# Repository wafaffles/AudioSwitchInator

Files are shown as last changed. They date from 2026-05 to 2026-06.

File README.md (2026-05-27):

# Audioswitchinator
A multi input and output audio switch with an integrated, toggleable Hifi phono preamp

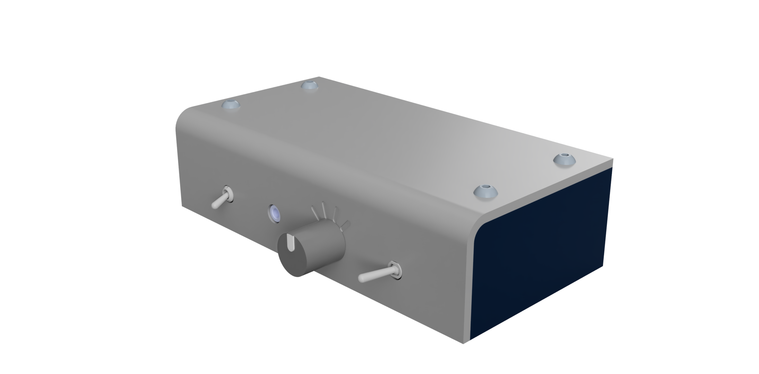
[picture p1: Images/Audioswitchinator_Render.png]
Render of Audioswitchinator in case


## Shortcuts
- [Features](#features)
- [What is it?](#what-is-it)
- [Resources](#resources)
- [Assembly](#assembly)
- [Bill Of Materials](#bill-of-materials)
- [Photos](#photos)

## Audioswitchinator Zine

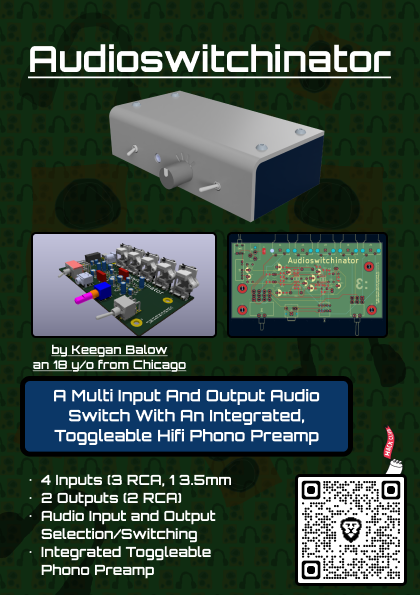
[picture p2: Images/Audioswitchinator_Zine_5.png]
Audioswitchinator Zine


## Features
- 4 Inputs
  - 3 RCA
  - 1 3.5mm
- 2 Outputs
  - 2 RCA
- Audio Input and Output Selection
- Integrated Toggleable Phono Preamp for a Turntable

## What is it?

The Audioswitchinator is a device that was made to allow me to route all of my audio inputs and outputs into one place on my desk so that I can easily change where my audio is coming from and going to without having to deal with changing the input on my speakers, changing the output on my computer, and my record player mainly. It features 4 inputs, 3 RCA and 1 3.5mm ports, and 2 ouputs, both being RCA ports. The first of the phono inputs is routed to a toggleable phono preamp, based on this design by [Elliott Sound Products](https://sound-au.com/project06.htm). The mixture of inputs and ports allows for easily compatibility with most audio products, as well as supporting smaller on the go inputs like a phone or other input device. While I only need 2 inputs and 2 outputs currently, the device features the extra inputs and outputs as my equipment arsenal expands or I want to test new products without fully removing the old ones.

The device features a power switch on the rear to power the integrated phono preamp, a switch on the front to enable routing of the turntable input through the phono preamp, a rotary switch to choose which input you would like to listen to, and a switch to choose between either of the two inputs.
It is powered using 12V via a 5.7mm barrell jack. It has a very low power draw of around 50mA at most so nearly any suitable 12V switching mode power supply should work well.

The case is fully 3d printed with use of a few M4 bolts and heatset inserts, but can easily be modified to thread directly into the plastic. The design resembles the design pattern of Schiit Audio products as I currently own a DAC and headphone amp and really like the design. The case is at largest 160x80, so it is easily printable on most 3D printers, being designed to print on my Bambu Labs A1 Mini.

## Resources

CAD Link: https://cad.onshape.com/documents/9e04128c642e582e05c8193e/w/29af00c33977f5103195c9e0/e/9dcbf64564f57b3e7e8e01ad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

CAD Files: [HERE](/Models)

ECAD Files: [HERE](/Models/ECAD/)

Production Files: [HERE](/Resources/)

## Assembly

You will need:
- PCB from files
- Soldering Iron & Solder
- All components from [BOM](https://docs.google.com/spreadsheets/d/1tNDlkv8S-ZhfvEyZw77WZDcWJRZpA8B7S98ZAzSkEbk/edit?usp=sharing.)
- Matching screwdriver to screw set (allen key in provided kit)
- Small pair of tweasers

To start, you will need to have access to a 3D printer with a build volume of at least 160x80mm and about 100-120g of filament of your choice.

You then need to order all the parts and PCB and have proper resources to solder these components. Once you have these, solder all components on as specified in the schematic.

Once soldered together where listed in the schematic, then with the bottom part of the case, insert the 8 heatset inserts if you choose not to modify the design to use those. To insert heatset inserts, get the largest tip that fits inside the heatset insert and install it on your soldering iron. Now, place the insert where it goes and insert the tip into the center of the insert snd heat it while applying slight downward force until it is flush with the surface. A small pair of tweasers may be helpful to reorient it.

Once all the heatset inserts are installed, you should be able to screw in the PCB, then screw on the top, and it should be working there!

## Bill Of Materials

Bill of Materials: [HERE](https://docs.google.com/spreadsheets/d/1tNDlkv8S-ZhfvEyZw77WZDcWJRZpA8B7S98ZAzSkEbk/edit?usp=sharing)

## Photos

Audioswitchinator PCB Schematic

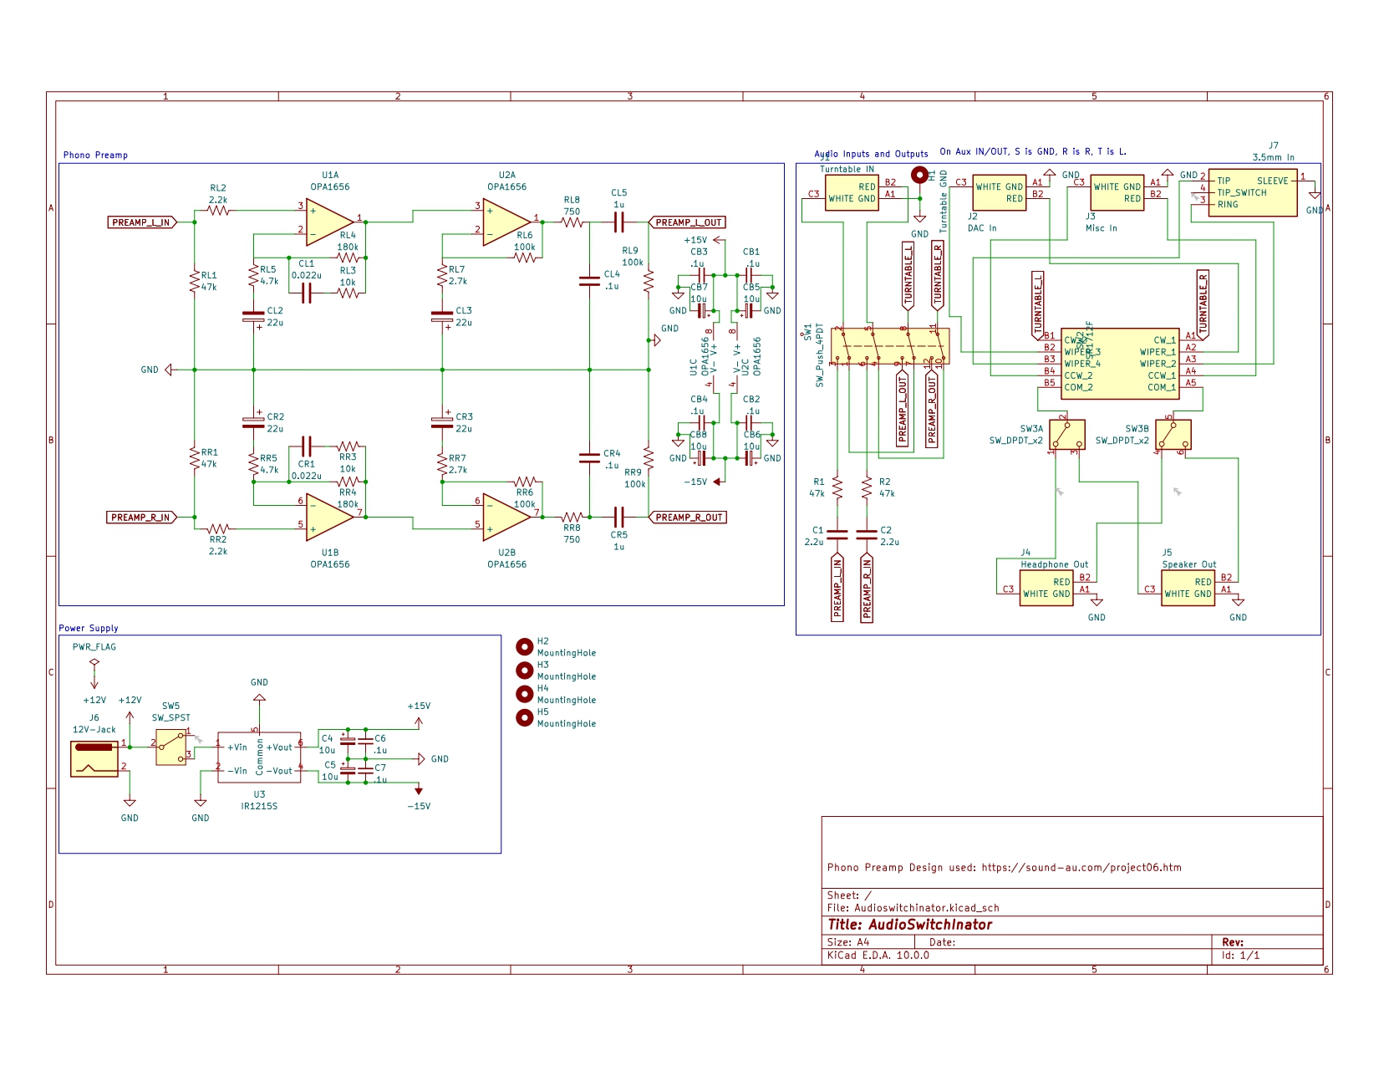
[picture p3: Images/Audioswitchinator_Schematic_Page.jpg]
Audioswitchinator PCB Schematic


Audioswitchinator Case Front

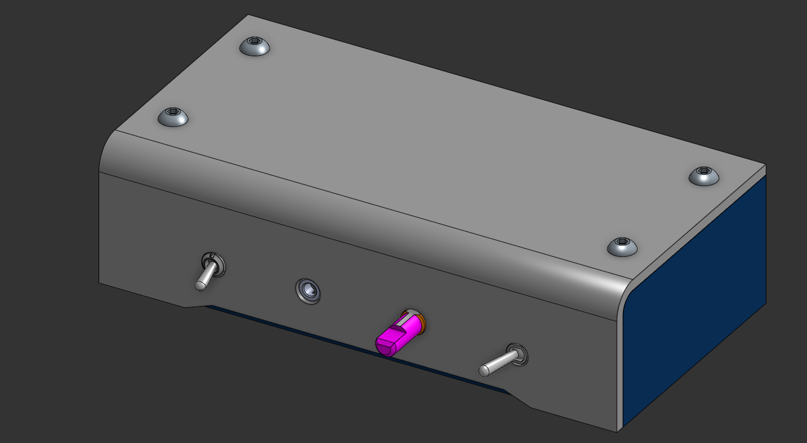
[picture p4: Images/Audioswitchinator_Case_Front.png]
Audioswitchinator Case Front


Audioswitchinator Case Back

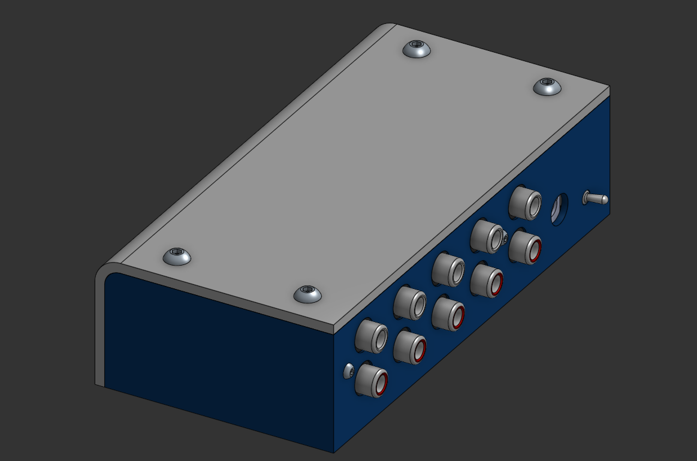
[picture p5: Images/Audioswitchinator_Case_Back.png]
Audioswitchinator Case Back


Audioswitchinator Case Inside

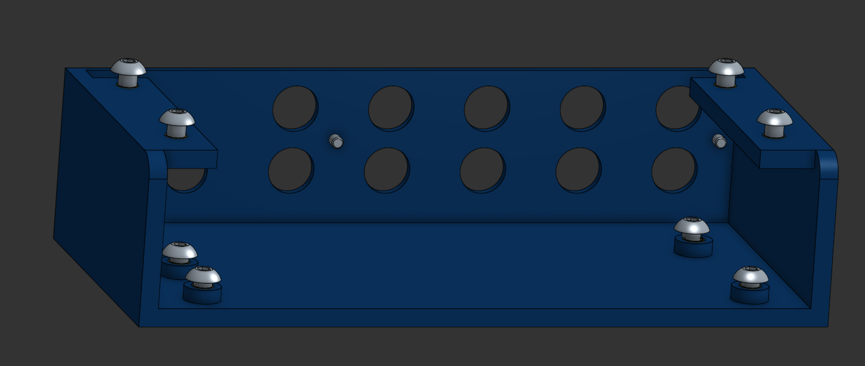
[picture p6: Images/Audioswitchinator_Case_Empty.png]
Audioswitchinator Case Inside


PCB All Layers

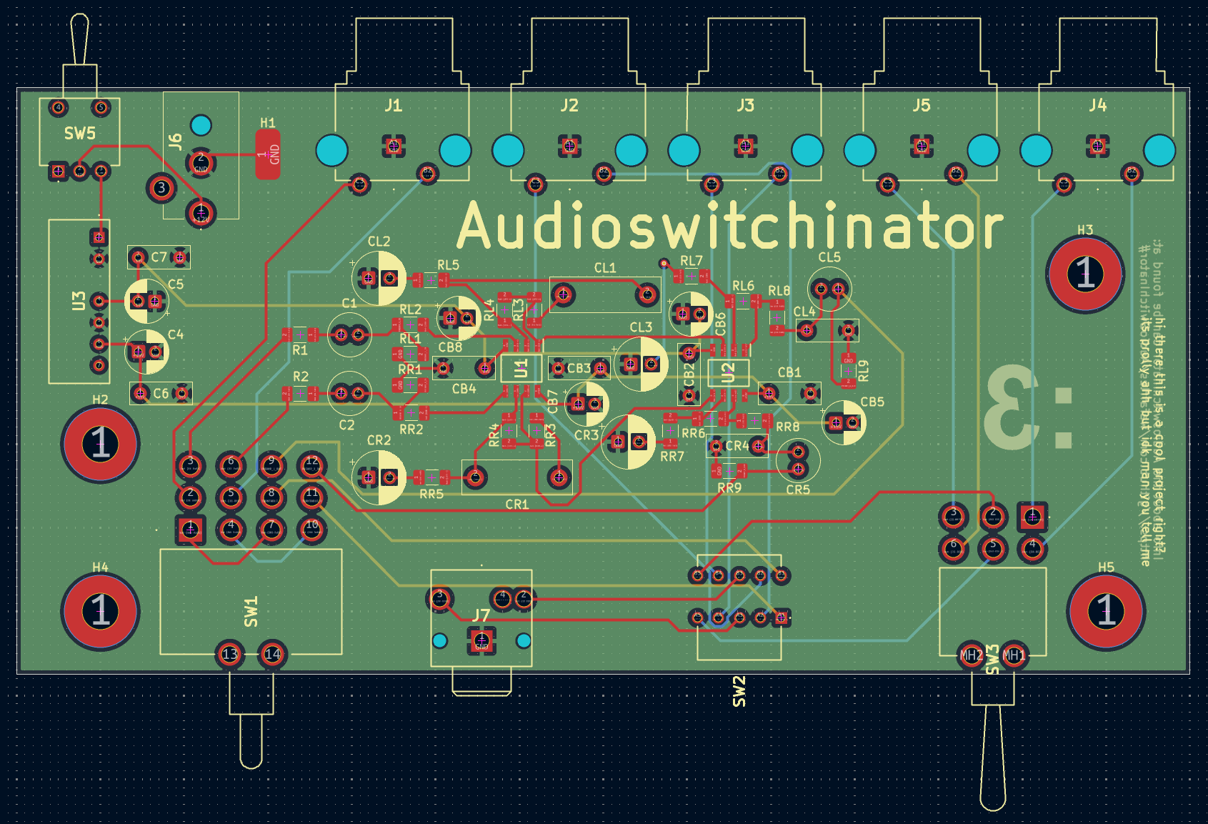
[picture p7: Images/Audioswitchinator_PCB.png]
PCB All Layers


PCB F.Cu Layer

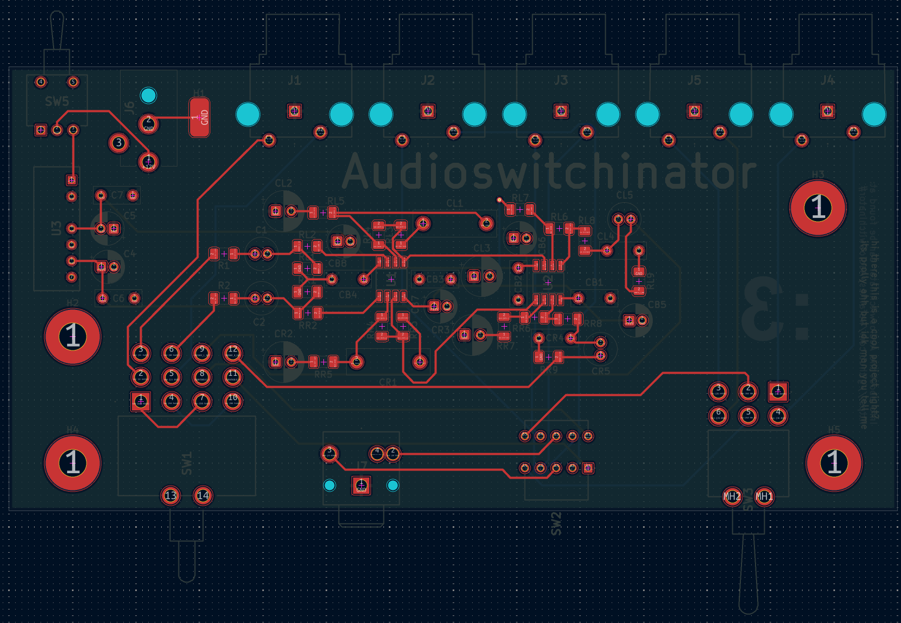
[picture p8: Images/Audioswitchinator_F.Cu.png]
PCB F.Cu Layer


PCB In1.Cu Layer

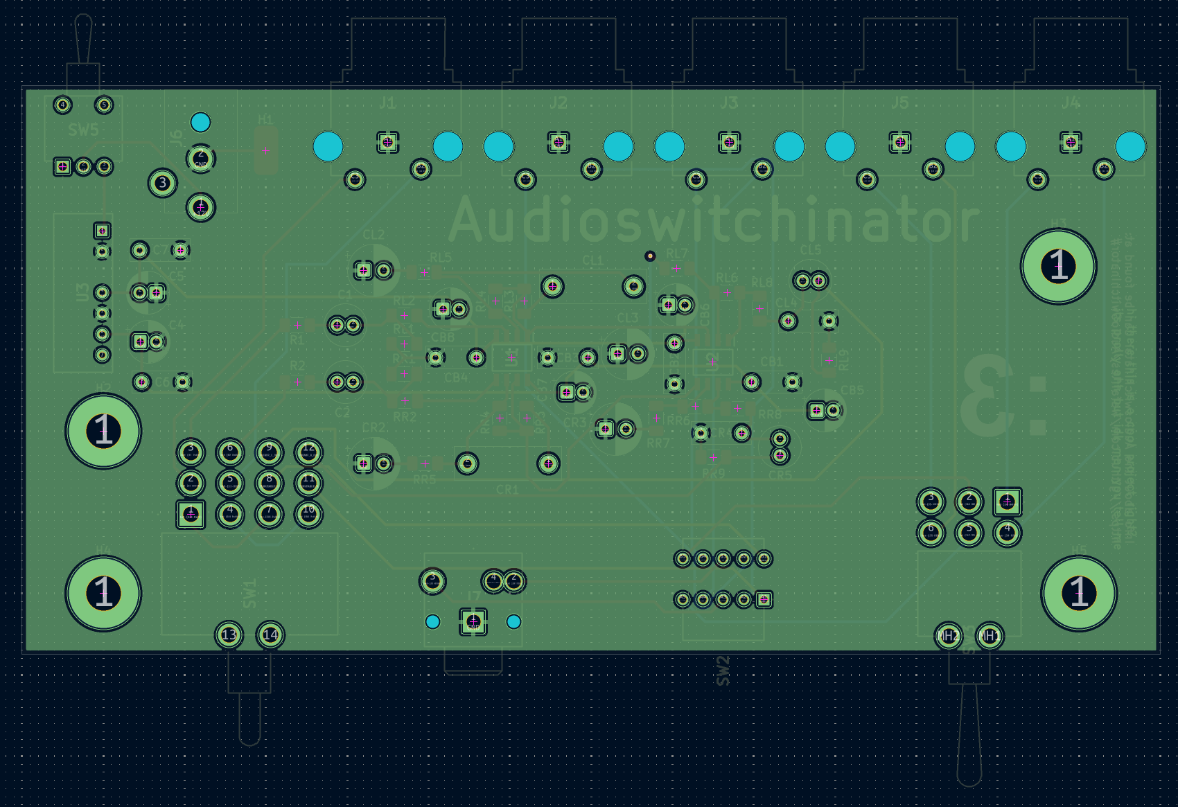
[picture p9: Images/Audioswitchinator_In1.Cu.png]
PCB In1.Cu Layer


PCB In2.Cu Layer

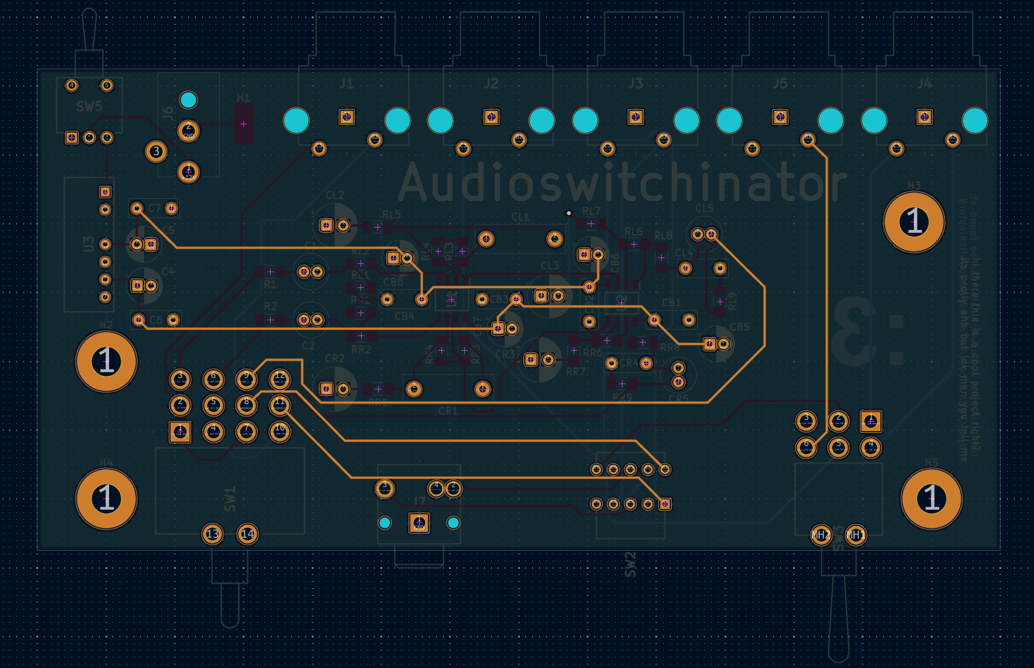
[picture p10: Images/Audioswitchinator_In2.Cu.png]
PCB In2.Cu Layer


PCB B.Cu Layer

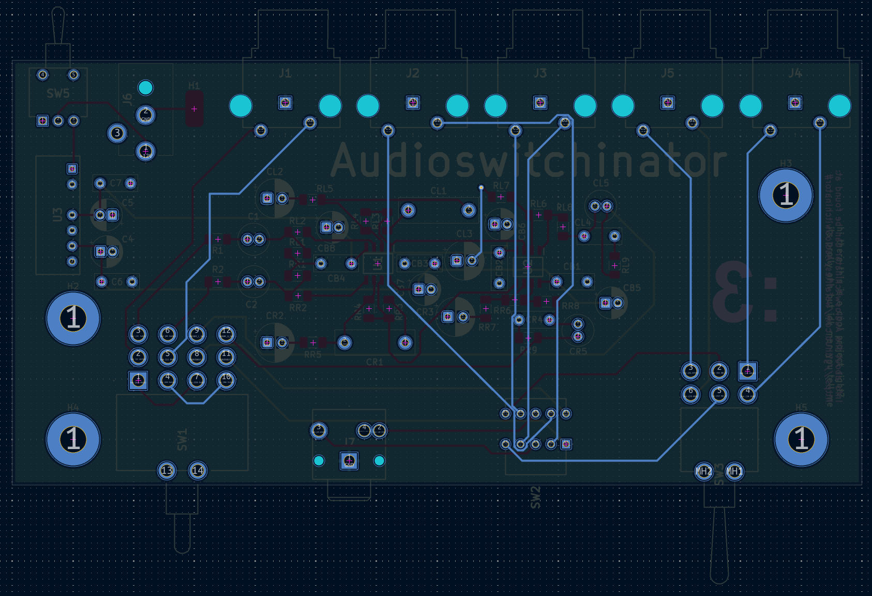
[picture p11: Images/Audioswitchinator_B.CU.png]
PCB B.Cu Layer


Fromt of PCB

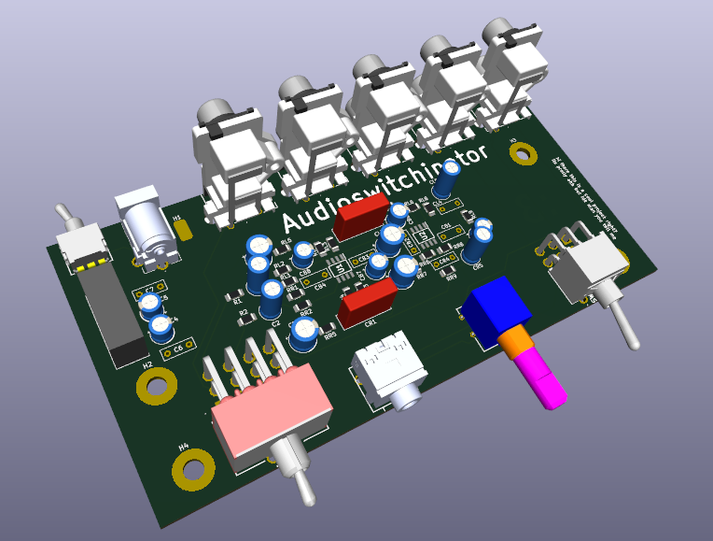
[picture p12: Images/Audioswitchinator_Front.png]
Front of PCB


Back of PCB

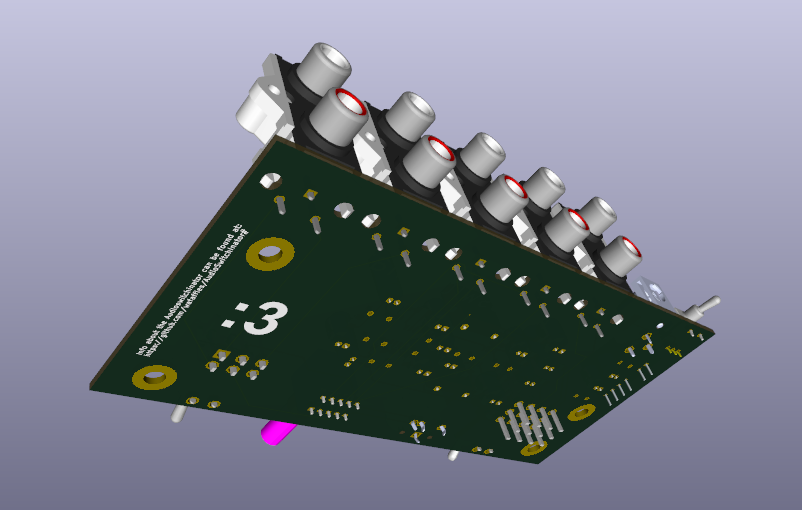
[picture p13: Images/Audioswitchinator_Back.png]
Back of PCB


## Credits

This project uses:

- [KiCad](https://www.kicad.org/)
- [Figma](https://www.figma.com/)
- [Hack Club Fallout](https://fallout.hackclub.com/path)

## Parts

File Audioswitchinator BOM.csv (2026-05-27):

Product Name | Part Number | Desc | Link | Unit Price | Qty | Total Price | Running Total
Operational Amplifiers - Op Amps SoundPlus ultra-low noise and distortio A 595-OPA1656ID | OPA1656IDR | OPA1656IDR Opamp, Amp in preamp | https://www.mouser.com/ProductDetail/Texas-Instruments/OPA1656IDR?qs=vLWxofP3U2ztlJVp%252BbIcnQ%3D%3D | $2.99 | 4 | $11.96 | $11.96
Aluminum Electrolytic Capacitors - Radial Leaded WCAP-AT1H 10uF 50V 20% Radial | 860240672002 | 10uF Capacitor, used in a variety of locations | https://www.mouser.com/ProductDetail/Wurth-Elektronik/860240672002?qs=0KOYDY2FL28MVrwKReUO5Q%3D%3D | $0.17 | 8 | $1.36 | $13.32
Aluminum Electrolytic Capacitors - Radial Leaded WCAP-AT1H 22uF 50V 20% Radial | 860240673003 | 22uF Capacitor, used in a variety of locations | https://www.mouser.com/ProductDetail/Wurth-Elektronik/860240673003?qs=0KOYDY2FL28JVTVT2XSgwQ%3D%3D | $0.19 | 6 | $1.14 | $14.46
Phone Connectors Audio Jacks | SJ1-3554NG | 3.5mm audio jack input | https://www.mouser.com/ProductDetail/Same-Sky/SJ1-3554NG?qs=WyjlAZoYn50FPSMJgVuxug%3D%3D | $0.57 | 2 | $1.14 | $15.60
DC Power Connectors Power Jacks | PJ-059A | DC power jack | https://www.mouser.com/ProductDetail/Same-Sky/PJ-059A?qs=WyjlAZoYn50bjj4Obx2X9w%3D%3D | $0.97 | 2 | $1.94 | $17.54
Thin Film Resistors - SMD | RT1206FRD0747KL | 47 kOhm Resistor | https://www.mouser.com/ProductDetail/YAGEO/RT1206FRD0747KL?qs=k2KEx2DUIRR1F0mE2a3ZUQ%3D%3D | $0.10 | 8 | $0.80 | $18.34
Thin Film Resistors - SMD 1/4W 2.2K ohm 1% 50ppm | RT1206FRE072K2L | 2.2 kOhm Resistor | https://www.mouser.com/ProductDetail/YAGEO/RT1206FRE072K2L?qs=yNCrj0CQcyJif6VASMbdeQ%3D%3D | $0.10 | 4 | $0.40 | $18.74
Thin Film Resistors - SMD 1/4W 10K ohm 1% 50ppm | RT1206FRE0710KL | 10 kOhm Resistor | https://www.mouser.com/ProductDetail/YAGEO/RT1206FRE0710KL?qs=8cPjvKtxWv45%2FSPYTvTNKg%3D%3D | $0.10 | 4 | $0.40 | $19.14
Thin Film Resistors - SMD 180K OHM 1% 50PPM 1/4W | RT1206FRE07180KL | 180 kOhm Resistor | https://www.mouser.com/ProductDetail/YAGEO/RT1206FRE07180KL?qs=yNCrj0CQcyKwf2yXFo5b%2FQ%3D%3D | $0.10 | 4 | $0.40 | $19.54
Thin Film Resistors - SMD 4.7K Ohm 1% 1/4W 200 Volts 50ppm | RT1206FRE074K7L | 4.7 kOhm Resistor | https://www.mouser.com/ProductDetail/YAGEO/RT1206FRE074K7L?qs=yNCrj0CQcyLcoH%2FB%252BiP%2FFQ%3D%3D | $0.10 | 4 | $0.40 | $19.94
Thin Film Resistors - SMD 1/4W 100K ohm 1% 50p pm | RT1206FRE07100KL | 100 kOhm Resistor | https://www.mouser.com/ProductDetail/YAGEO/RT1206FRE07100KL?qs=8cPjvKtxWv7PtFSw4u2eIw%3D%3D | $0.10 | 8 | $0.80 | $20.74
Thin Film Resistors - SMD 1/4W 2.7K ohm 1% 50ppm | RT1206FRE072K7L | 2.7 kOhm Resistor | https://www.mouser.com/ProductDetail/YAGEO/RT1206FRE072K7L?qs=Fz%2FrpjPuTcHFMKRq4MRJ%2Fg%3D%3D | $0.10 | 4 | $0.40 | $21.14
Thin Film Resistors - SMD 1/4W 750 ohm 1% 50ppm | RT1206FRE07750RL | 750 Ohm Resistor | https://www.mouser.com/ProductDetail/YAGEO/RT1206FRE07750RL?qs=Fz%2FrpjPuTcHGMql1%2FTp2YA%3D%3D | $0.10 | 4 | $0.40 | $21.54
Toggle Switches 5A 120VAC/28VDC On-Off-On PC Mnt | 1004P3T2B4M7QE | 4PDT toggle switch for preamp selection | https://www.mouser.com/ProductDetail/E-Switch/1004P3T2B4M7QE?qs=f57gQzlyLiqFzMrosyOsSw%3D%3D | $11.60 | 1 | $11.60 | $33.14
Toggle Switches SPDT, ON-ON, 6mm toggle, 4mm smooth bushing, right angle PC terminals with .3" pitch, 50mA @ 60V AC/DC, washable | ATE1D-6M3-10-Z | SPDT toggle switch for preamp power | https://www.mouser.com/ProductDetail/Nidec/ATE1D-6M3-10-Z?qs=XeJtXLiO41ReBOz5v17RPA%3D%3D | $3.60 | 1 | $3.60 | $36.74
DC/DC Converters - Through Hole DC-DC, 3W semi-reg., dual output, SIP | IR1215S | 12V-15V DC converter to power preamp | https://www.mouser.com/ProductDetail/XP-Power/IR1215S?qs=w%2Fv1CP2dgqp75iaPc7854Q%3D%3D | $10.71 | 1 | $10.71 | $47.45
Toggle Switches 5A 120VAC/28VDC On-None-On PC Mnt | 100AWDP1T1B4M6QE | DPDT Switch for output selection | https://www.mouser.com/ProductDetail/E-Switch/100AWDP1T1B4M6QE?qs=f57gQzlyLiof%2FBzhsgALbA%3D%3D | $3.95 | 1 | $3.95 | $51.40
RCA Phono Connectors RCA Phono Jack White, Red | 156-4219-E | RCA phono connectors for I/O | https://www.mouser.com/ProductDetail/Kobiconn/156-4219-E?qs=DPoM0jnrROUdVj8su1y9tg%3D%3D | $1.03 | 7 | $7.21 | $58.61
Rotary Switches 4 Pos 0.1 Amp at 16 Volts | SRBM149501 | 4 position 2 pole rotary switch for input selection | https://www.mouser.com/ProductDetail/Alps-Alpine/SRBM149501?qs=nco%2F1JLdfbeZ5Szj64Y%252BGA%3D%3D | $5.62 | 1 | $5.62 | $64.23
Film Capacitors 0.022 uF 250 VDC 5% | MKP1F022203C00JSSD | 0.022uF Capacitor | https://www.mouser.com/ProductDetail/WIMA/MKP1F022203C00JSSD?qs=OanN%252B0kfw%2FYfJXvyN0rUYQ%3D%3D | $0.60 | 4 | $2.40 | $66.63
Aluminum Electrolytic Capacitors - Radial Leaded WCAP-ATG8 1uF 50V 20% Radial | 860010672005 | 1uF Capacitor | https://www.mouser.com/ProductDetail/Wurth-Elektronik/860010672005?qs=0KOYDY2FL2%2Fygsu5JxD2ZQ%3D%3D | $0.11 | 6 | $0.66 | $67.29
Aluminum Electrolytic Capacitors - Radial Leaded WCAP-ATG8 2.2uF 50V 20% Radial | 860010672006 | 2.2uF Capacitor | https://www.mouser.com/ProductDetail/Wurth-Elektronik/860010672006?qs=0KOYDY2FL29lPsrXIuQ3HA%3D%3D | $0.12 | 6 | $0.72 | $68.01
Film Capacitors .1UF 63V 5% | MKS2C031001A00JSSD | 0.1uF Capacitor | https://www.mouser.com/ProductDetail/WIMA/MKS2C031001A00JSSD?qs=HY1Oqu7CRgrW1XsZMv8Ccg%3D%3D | $0.37 | 12 | $4.42 | $72.43
Mouser Shipping |  |  |  | $8.49 | 1 | $8.49 | $80.92
Mouser Tariffs as of 5/25/26 |  |  |  | $9.39 | 1 | $9.39 | $90.31
JLC PCBs | N/A | PCBs |  | $29.30 | 1 | $29.30 | $119.61
JLCPCB Shipping |  |  |  | $3.30 | 1 | $3.30 | $122.91
ELEGOO Matte PLA Filament Navy Blue 1KG, 1.75mm 3D Printer Filament Dimensional Accuracy +/- 0.02mm, 1kg Carboard Spool (2.2lbs) Fits for Most FDM 3D Printers | N/A | 1Kg Elegoo Matte Navy Blue PLA | https://www.amazon.com/dp/B0CFV4WLY6/ | $20.99 | 1 | $20.99 | $143.90
ELEGOO Matte PLA Filament Matte Black 1KG, 1.75mm 3D Printer Filament Dimensional Accuracy +/- 0.02mm, 1kg Carboard Spool (2.2lbs) Fits for Most FDM 3D Printers | N/A | 1Kg Elegoo Matte Black PLA | https://www.amazon.com/dp/B0CFV3WF7P/ref=twister_B0CQCGWZPZ?_encoding=UTF8 | $16.99 | 1 | $16.99 | $160.89
VIGRUE 570Pcs M5 M4 M3 Button Head Socket Cap Screws Bolts Nuts Washers Assortment Kit, Black Small Metric Screws Set Assortment, 10.9 Grade Alloy Steel | N/A | Assorted bolt set I already have with M4 bolts | https://www.amazon.com/dp/B07HVRJW5J | $21.99 | 1 | $21.99 | $182.88
Hilitchi 460 Pcs M2 M3 M4 M5 Female Thread Brass Knurled Threaded Insert Embedment Nuts Assortment Kit, Embed Parts, Pressed Fit into Holes for 3D Prints and More Projects | N/A | Assorted heatset inswrt set I already have with M4 heatset inserts | https://www.amazon.com/dp/B07VFZWWXY | $20.99 | 1 | $20.99 | $203.87
 |  |  |  |  |  | Total | $203.87
 |  |  |  |  |  | Total To Buy | $160.89

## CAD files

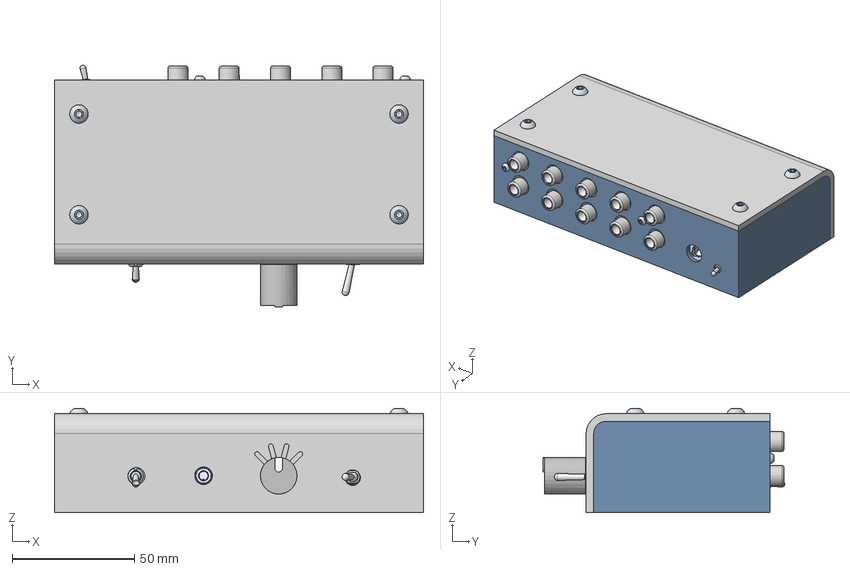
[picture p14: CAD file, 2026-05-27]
Models/Audioswitchinator Assembly.step
151.0 x 98.9 x 42.7 mm
M4x4mm Heatset Insert x 8
Socket button head screw M2.5x0.45 x 5 x 2
Socket button head screw M4x0.7 x 8 x 8
Top
Knob
Bottom
Audioswitchinator_silkscreen x 479
CP_Radial_D5.0mm_P2.00mm x 6
CP_Radial_D6.3mm_P2.50mm x 4
156-4219-E x 5
R_1206_3216Metric x 20
100AWDPxT1B4M6xE x 7
C_Radial_D5.0mm_H11.0mm_P2.00mm x 4
SRBM149501
Audioswitchinator_PCB
SJ1-3554NG
C_Rect_L13.0mm_W4.0mm_P10.00mm_FKS3_FKP3_MKS4 x 2
PJ-059A
Leads x 6
1001A-2
3004A-332
2004A1_(ATE)
3004A-32
3004A-232
1001A-1

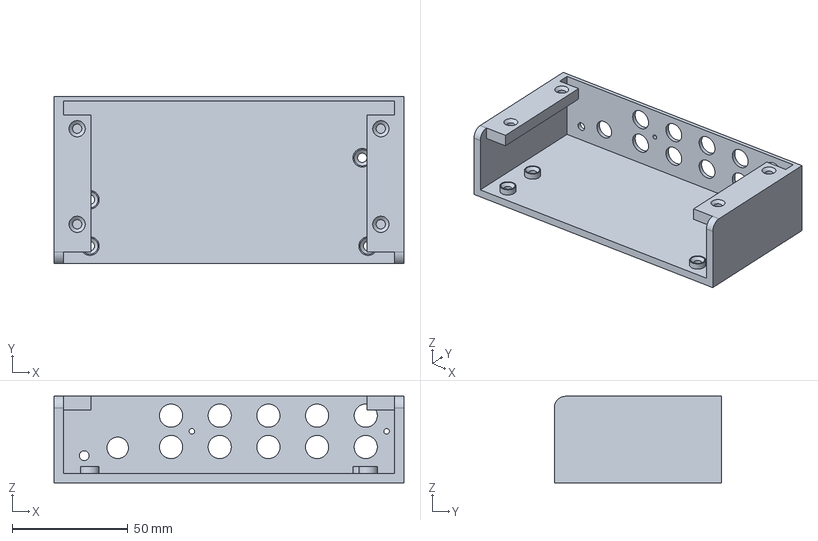
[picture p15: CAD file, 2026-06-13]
Models/Audioswitchinator Case - Bottom.step
151.0 x 72.2 x 37.4 mm

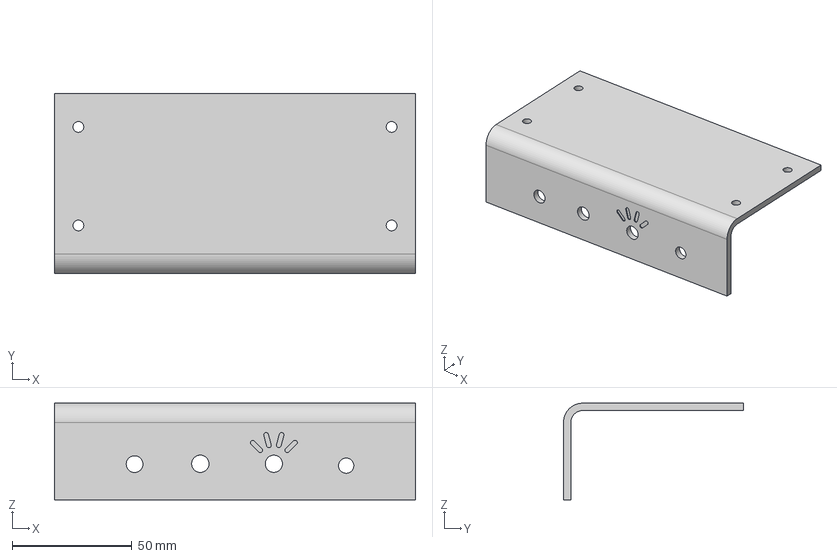
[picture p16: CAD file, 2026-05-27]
Models/Audioswitchinator Case - Top.step
151.0 x 75.3 x 40.5 mm

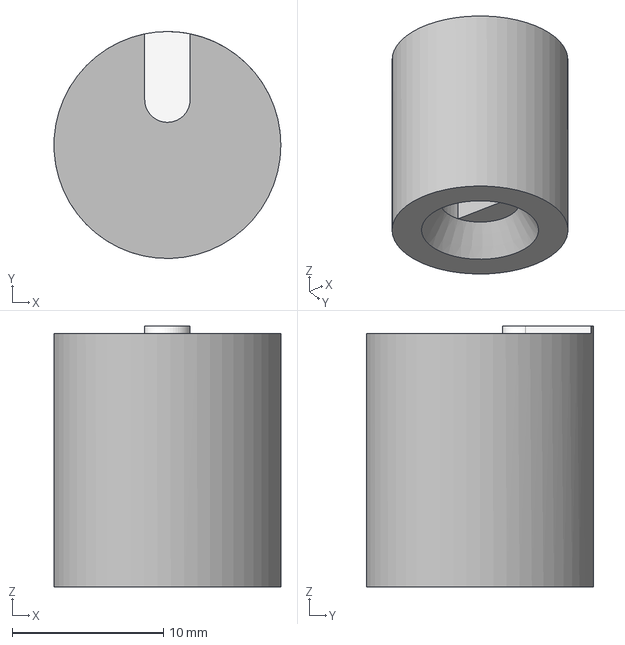
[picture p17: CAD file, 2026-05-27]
Models/Audioswitchinator - Knob.step
15.0 x 15.0 x 17.2 mm

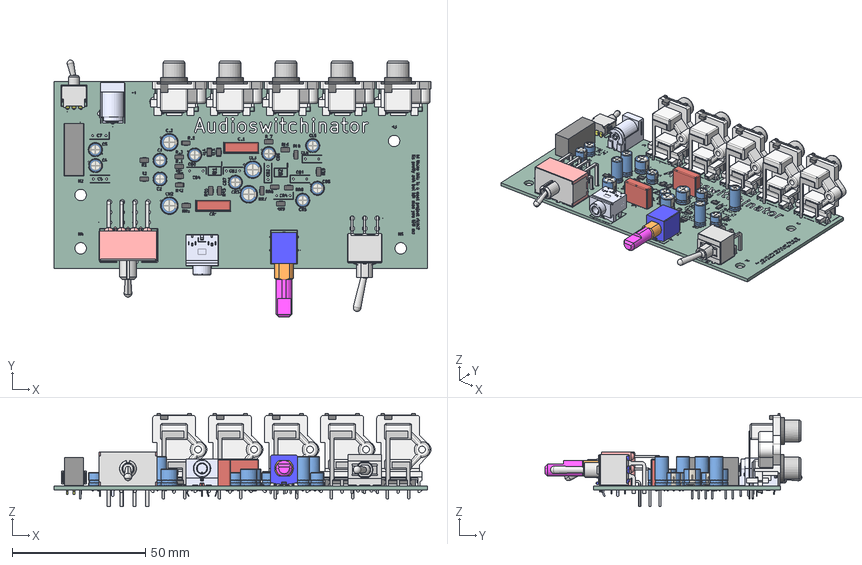
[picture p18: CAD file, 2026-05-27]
Models/Audioswitchinator_PCB_model.step
141.3 x 96.4 x 35.0 mm
CP_Radial_D6.3mm_P2.50mm x 4
Leads
C_Radial_D5.0mm_H11.0mm_P2.00mm x 4
R_1206_3216Metric x 20
CP_Radial_D5.0mm_P2.00mm x 6
156-4219-E x 5
PJ-059A
SRBM149501
100AWDPxT1B4M6xE
2004A1_(ATE)
1001A-1
1001A-2
3004A-332
3004A-232
3004A-32
C_Rect_L13.0mm_W4.0mm_P10.00mm_FKS3_FKP3_MKS4 x 2
SJ1-3554NG
Audioswitchinator_silkscreen x 2
Audioswitchinator_PCB

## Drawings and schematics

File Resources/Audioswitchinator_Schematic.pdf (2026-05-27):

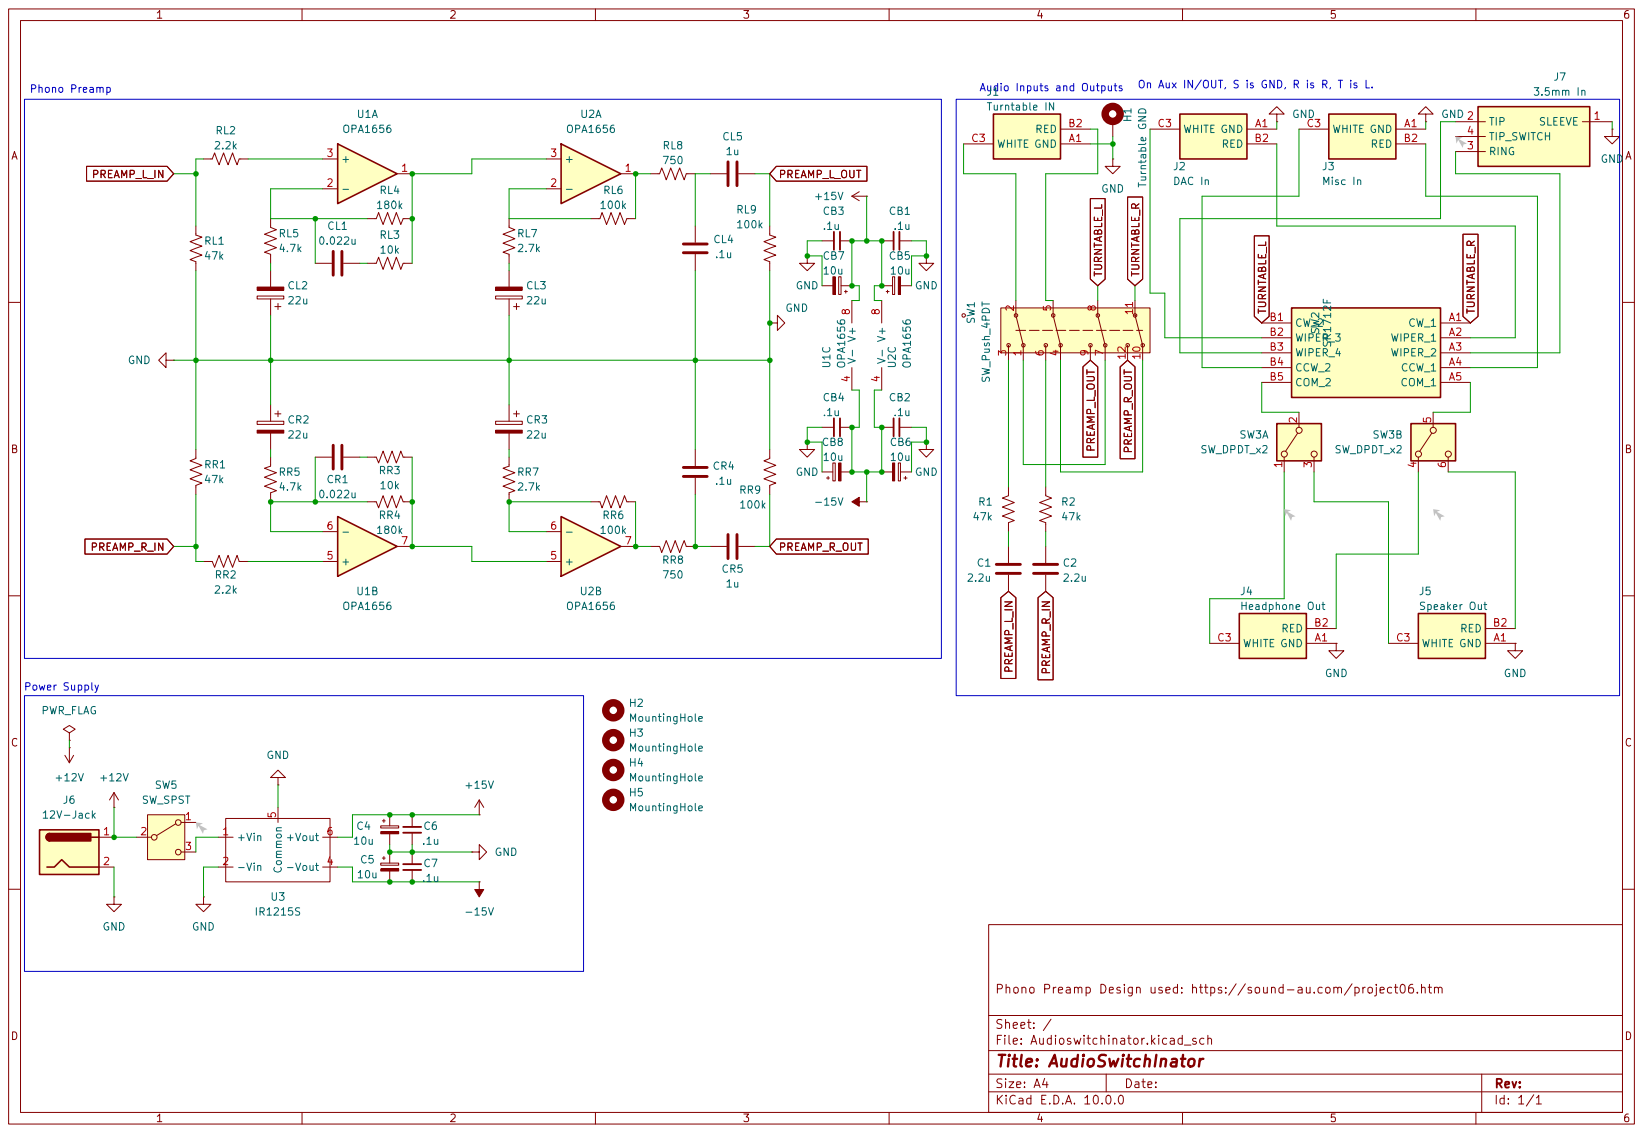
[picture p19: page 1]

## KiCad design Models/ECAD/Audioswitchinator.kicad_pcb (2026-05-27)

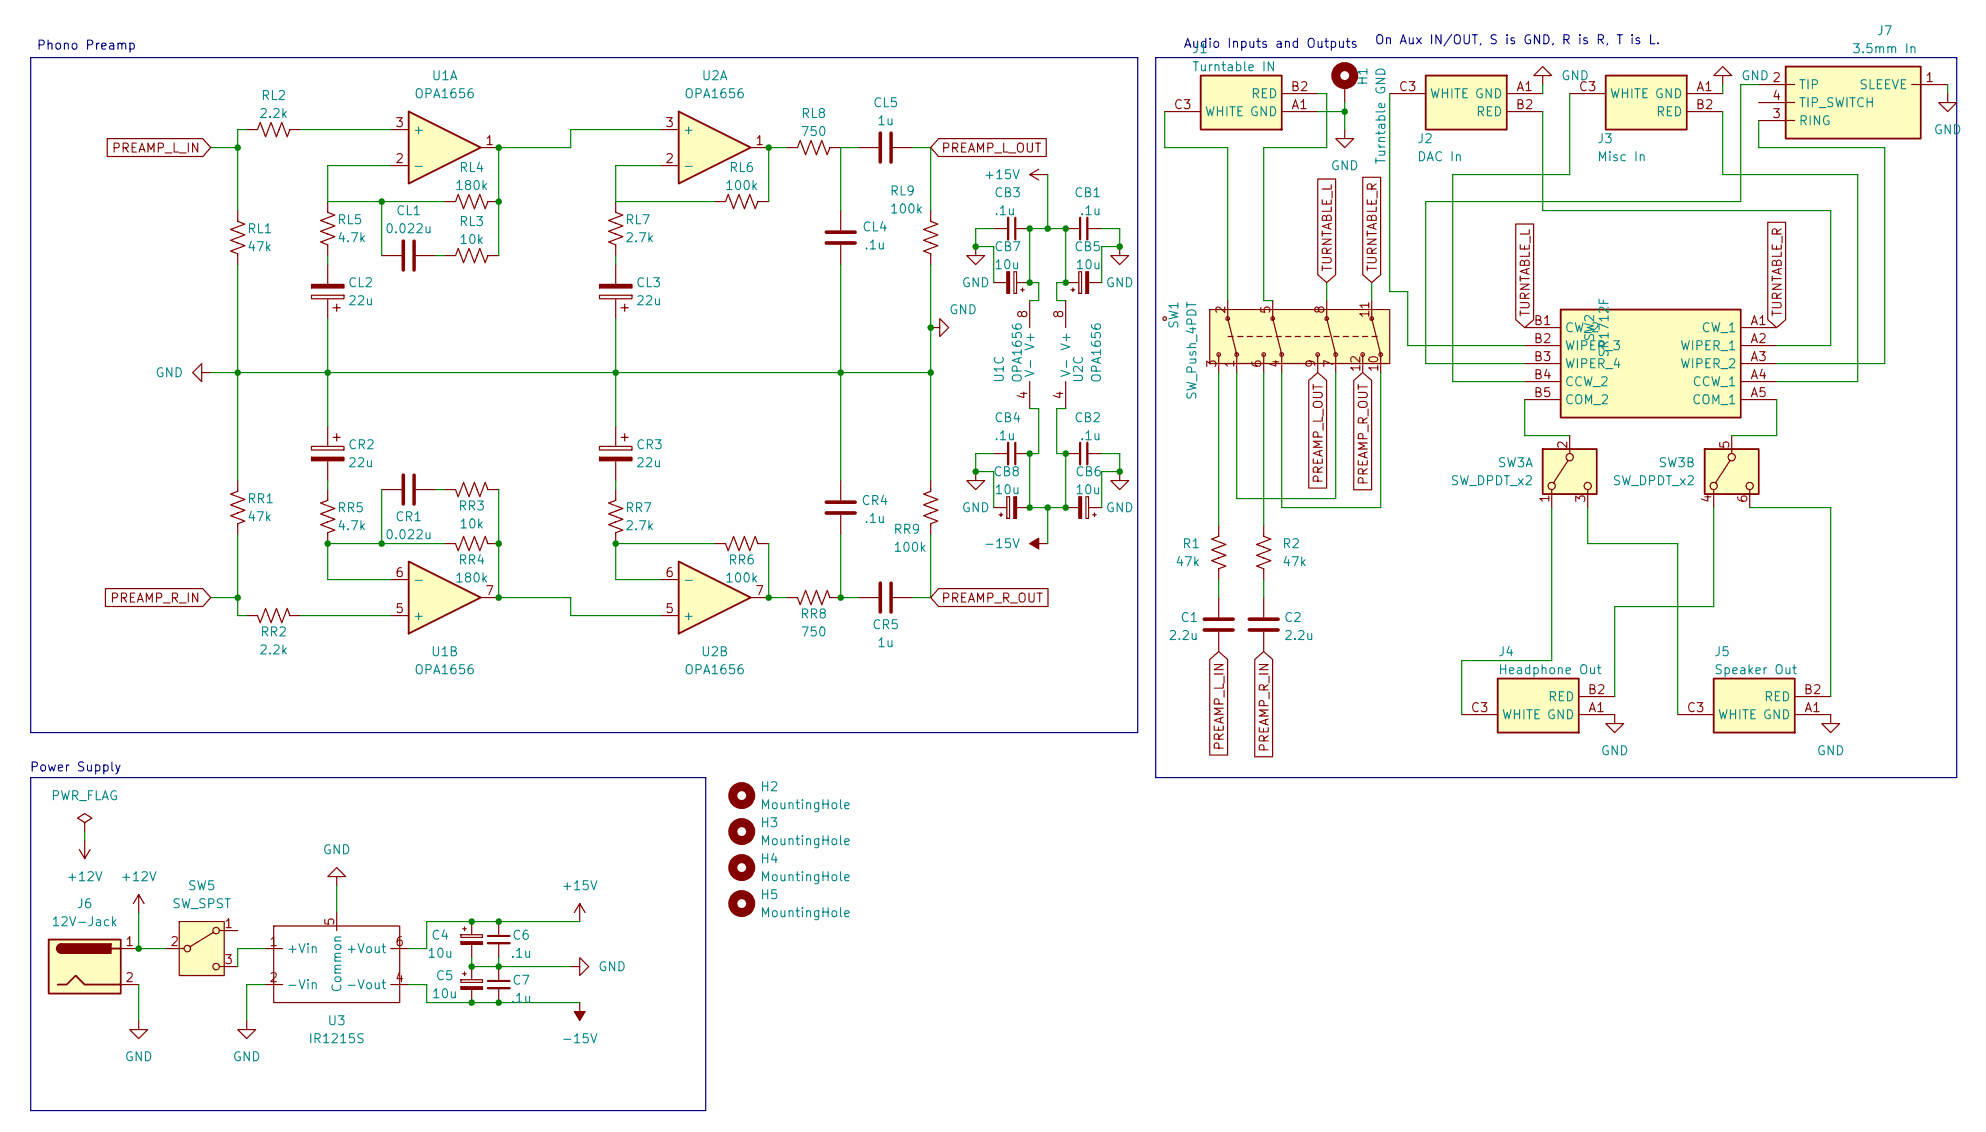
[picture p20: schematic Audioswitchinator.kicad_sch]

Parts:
C1, C2: 2.2u; C_Radial_D5.0mm_H11.0mm_P2.00mm
C4, C5: 10u; CP_Radial_D5.0mm_P2.00mm
C6, C7: .1u; C_Rect_L7.2mm_W2.5mm_P5.00mm
CB1, CB2, CB3, CB4: .1u; C_Rect_L7.2mm_W2.5mm_P5.00mm
CB5, CB6, CB7, CB8: 10u; CP_Radial_D5.0mm_P2.00mm
CL1: 0.022u; C_Rect_L13.0mm_W4.0mm_P10.00mm_FKS3_FKP3_MKS4
CL2, CL3: 22u; CP_Radial_D6.3mm_P2.50mm
CL4: .1u; C_Rect_L7.2mm_W2.5mm_P5.00mm
CL5: 1u; C_Radial_D5.0mm_H11.0mm_P2.00mm
CR1: 0.022u; C_Rect_L13.0mm_W4.0mm_P10.00mm_FKS3_FKP3_MKS4
CR2, CR3: 22u; CP_Radial_D6.3mm_P2.50mm
CR4: .1u; C_Rect_L7.2mm_W2.5mm_P5.00mm
CR5: 1u; C_Radial_D5.0mm_H11.0mm_P2.00mm
H1: Turntable GND; SolderWirePad_1x01_SMD_3x6mm
H2, H3, H4, H5: MountingHole; MountingHole_4.3mm_M4_Pad
J1: Turntable IN; 1564219E; Manufacturer_Part_Number 156-4219-E
J2: DAC In; 1564219E; Manufacturer_Part_Number 156-4219-E
J3: Misc In; 1564219E; Manufacturer_Part_Number 156-4219-E
J4: Headphone Out; 1564219E; Manufacturer_Part_Number 156-4219-E
J5: Speaker Out; 1564219E; Manufacturer_Part_Number 156-4219-E
J6: 12V-Jack; PJ059A
J7: 3.5mm In; SJ13554NG; Manufacturer_Part_Number SJ1-3554NG
R1, R2: 47k; R_1206_3216Metric_Pad1.30x1.75mm_HandSolder
RL1: 47k; R_1206_3216Metric_Pad1.30x1.75mm_HandSolder
RL2: 2.2k; R_1206_3216Metric_Pad1.30x1.75mm_HandSolder
RL3: 10k; R_1206_3216Metric_Pad1.30x1.75mm_HandSolder
RL4: 180k; R_1206_3216Metric_Pad1.30x1.75mm_HandSolder
RL5: 4.7k; R_1206_3216Metric_Pad1.30x1.75mm_HandSolder
RL6, RL9: 100k; R_1206_3216Metric_Pad1.30x1.75mm_HandSolder
RL7: 2.7k; R_1206_3216Metric_Pad1.30x1.75mm_HandSolder
RL8: 750; R_1206_3216Metric_Pad1.30x1.75mm_HandSolder
RR1: 47k; R_1206_3216Metric_Pad1.30x1.75mm_HandSolder
RR2: 2.2k; R_1206_3216Metric_Pad1.30x1.75mm_HandSolder
RR3: 10k; R_1206_3216Metric_Pad1.30x1.75mm_HandSolder
RR4: 180k; R_1206_3216Metric_Pad1.30x1.75mm_HandSolder
RR5: 4.7k; R_1206_3216Metric_Pad1.30x1.75mm_HandSolder
RR6, RR9: 100k; R_1206_3216Metric_Pad1.30x1.75mm_HandSolder
RR7: 2.7k; R_1206_3216Metric_Pad1.30x1.75mm_HandSolder
RR8: 750; R_1206_3216Metric_Pad1.30x1.75mm_HandSolder
SW1: SW_Push_4PDT; 1004P3T2B4M7QE
SW2: SR1712F; SRBM149501; Mouser Part Number 688-SRBM149501
SW3: SW_DPDT_x2; 100AWDP1T1B4M6QE
SW5: SW_SPST; ATE1D6M310Z
U1, U2: OPA1656; SOIC127P600X175-8N-OPA1656IDR
U3: IR1215S

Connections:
+12V: J6.1, SW5.2 (B)
+15V: C4.1, C6.1, CB1.1, CB3.1, CB5.1, CB7.1, U1.8 (V+), U2.8 (V+), U3.6 (+Vout)
-15V: C5.2, C7.2, CB2.1, CB4.1, CB6.2, CB8.2, U1.4 (V-), U2.4 (V-), U3.4 (-Vout)
GND: C4.2, C5.1, C6.2, C7.1, CB1.2, CB2.2, CB3.2, CB4.2, CB5.2, CB6.1, CB7.2, CB8.1, CL2.1, CL3.1, CL4.2, CR2.1, CR3.1, CR4.2, H1.1 (1_1), J1.A1 (GND), J2.A1 (GND), J3.A1 (GND), J4.A1 (GND), J5.A1 (GND), J6.2, J7.1 (SLEEVE), RL1.1, RL9.1, RR1.1, RR9.1, U3.2 (-Vin), U3.5 (Common)
unnamed: C1.1, R1.1
unnamed: C2.1, R2.1
unnamed: CL1.1, RL3.1
unnamed: CL2.2, RL5.1
unnamed: CL3.2, RL7.1
unnamed: CL4.1, CL5.2, RL8.2
unnamed: CR1.1, RR3.1
unnamed: CR2.2, RR5.1
unnamed: CR3.2, RR7.1
unnamed: CR4.1, CR5.2, RR8.2
unnamed: J1.B2 (RED), SW1.5
unnamed: J1.C3 (WHITE), SW1.2
unnamed: J2.B2 (RED), SW2.A2 (WIPER_1)
unnamed: J2.C3 (WHITE), SW2.B2 (WIPER_3)
unnamed: J3.B2 (RED), SW2.A4 (CCW_1)
unnamed: J3.C3 (WHITE), SW2.B4 (CCW_2)
unnamed: J4.B2 (RED), SW3.4 (A)
unnamed: J4.C3 (WHITE), SW3.1 (A)
unnamed: J5.B2 (RED), SW3.6 (C)
unnamed: J5.C3 (WHITE), SW3.3 (C)
unnamed: J7.3 (RING), SW2.A3 (WIPER_2)
unnamed: J7.2 (TIP), SW2.B3 (WIPER_4)
unnamed: R1.2, SW1.3
unnamed: R2.2, SW1.6
unnamed: RL6.2, RL8.1, U2.1
unnamed: RR6.2, RR8.1, U2.7
unnamed: SW1.1, SW1.7
unnamed: SW1.4, SW1.10
unnamed: SW2.A5 (COM_1), SW3.5 (B)
unnamed: SW2.B5 (COM_2), SW3.2 (B)
unnamed: SW5.3 (C), U3.1 (+Vin)
unnamed: RL2.2, U1.3 (+)
unnamed: CL1.2, RL4.1, RL5.2, U1.2 (-)
unnamed: RR2.2, U1.5 (+)
unnamed: CR1.2, RR4.1, RR5.2, U1.6 (-)
unnamed: RL3.2, RL4.2, U1.1, U2.3 (+)
unnamed: RL6.1, RL7.2, U2.2 (-)
unnamed: RR3.2, RR4.2, U1.7, U2.5 (+)
unnamed: RR6.1, RR7.2, U2.6 (-)
PREAMP_L_IN: C1.2, RL1.2, RL2.1
PREAMP_L_OUT: CL5.1, RL9.2, SW1.9
PREAMP_R_IN: C2.2, RR1.2, RR2.1
PREAMP_R_OUT: CR5.1, RR9.2, SW1.12
TURNTABLE_L: SW1.8, SW2.B1 (CW_2)
TURNTABLE_R: SW1.11, SW2.A1 (CW_1)

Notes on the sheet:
Power Supply
Audio Inputs and Outputs
On Aux IN/OUT, S is GND, R is R, T is L.
Phono Preamp

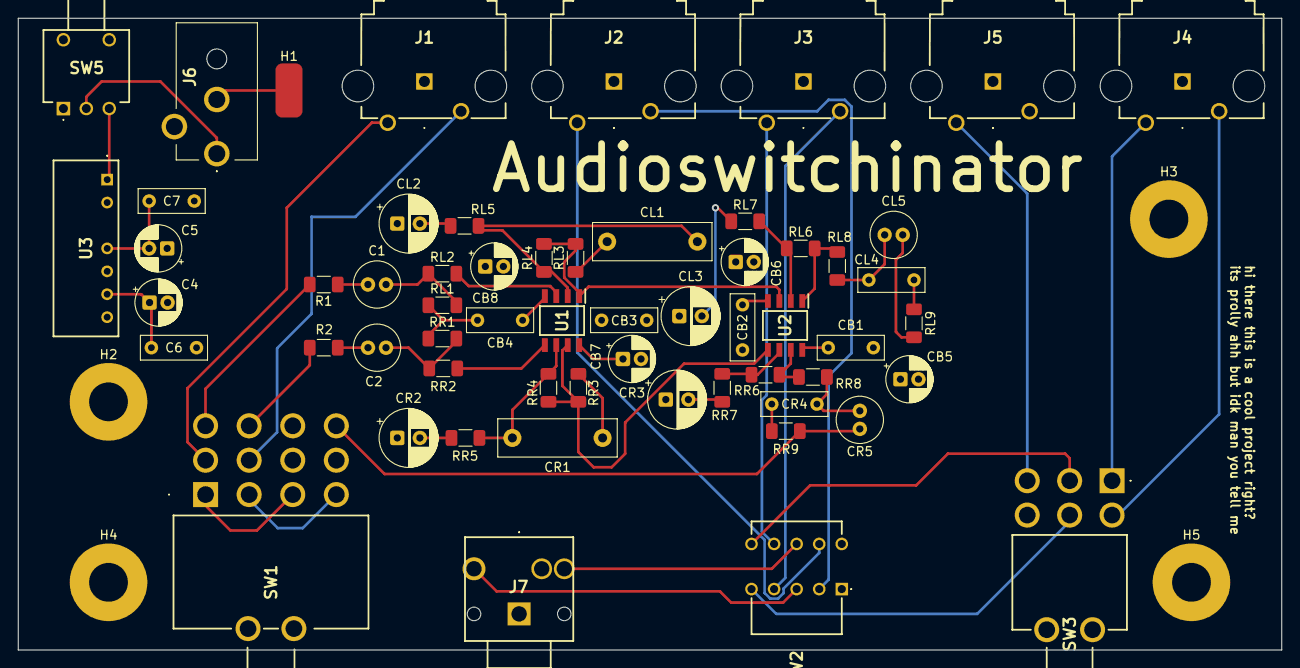
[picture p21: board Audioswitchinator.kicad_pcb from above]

Board: 4 copper layers, 140.0 x 70.0 mm, 63 parts (0 on the bottom side), 49 nets.

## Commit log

2026-05-23 Update README.md
    Created first version of README, need to add BOM and files next
2026-05-25 Added Image, Fab, and Cad Files
    [.step, Audioswitchinator Case - Bottom.step, Audioswitchinator Case - Top.step]
2026-05-25 upload ECAD files
    [Audioswitchinator.kicad_pcb]
2026-05-27 Sync local files with remote
    [Audioswitchinator.kicad_pcb, Audioswitchinator.kicad_sch]
2026-05-27 Update Audioswitchinator BOM.csv
    [Audioswitchinator BOM.csv]
2026-06-13 Update Audioswitchinator Case - Bottom.step
    [Audioswitchinator Case - Bottom.step]
